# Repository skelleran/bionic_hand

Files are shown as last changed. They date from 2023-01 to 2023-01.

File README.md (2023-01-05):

# bionic_hand
A bionic hand controlled by a Raspberry Pi 4 connected to an ultrasonic sensor and camera. Uses TensorFlow Lite to detect objects and determine how to control the five connected servos.

pros_hand.py is the main code. I run it in a virtual environment on the Raspberry Pi 4, and it performs the full functionality described above. It requires the detection_model folder contents to perform object detection with Tensorflow Lite. Much of the object detection code was originally based on this sample code:
https://github.com/AnteZovko23/Machine_Learning-RaspberryPI_ObjectDetection_TensorFlow_OpenCV/blob/master/ObjectDetection2.py

detection_model contains the trained model, along with a text document, gripinfo.txt, that contains important information for pros_hand.py. The first column in the document contains labels for each possible classification, which is referenced by the index outputted by the trained model. The next five columns contain finger positions for their respective object so that pros_hand.py can specialize the grip to the targeted object.

solidworks_parts contains the parts I used to design the hand in solidworks. I recommend using the assembly to navigate between parts. Almost everything in the folder was designed by myself, with these exceptions:

Raspberry Pi Camera: https://grabcad.com/library/raspberry-pi-camera-v2-1

MG996R Servo: https://grabcad.com/library/servo-mg-996r-2

Ultrasonic Sensor: https://grabcad.com/library/ultrasonic-sensor-hc-sr04-5

printable_stl_parts contains stl parts exported from solidworks for printing, and everything in it is my original design.

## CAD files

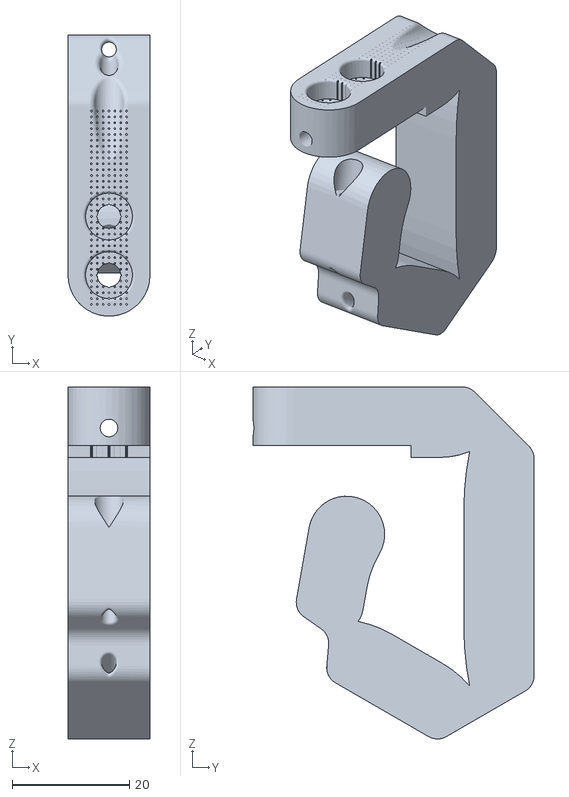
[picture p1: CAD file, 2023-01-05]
printable_stl_parts/Index Finger v2.STL
14.0 x 48.0 x 60.1

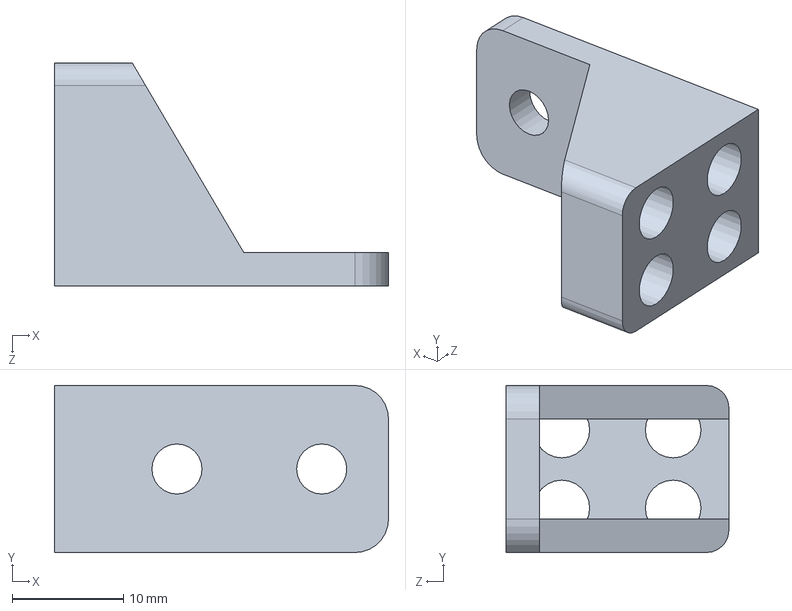
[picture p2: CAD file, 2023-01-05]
solidworks_parts/Servo Bracket.SLDPRT
30.0 x 15.0 x 20.0 mm

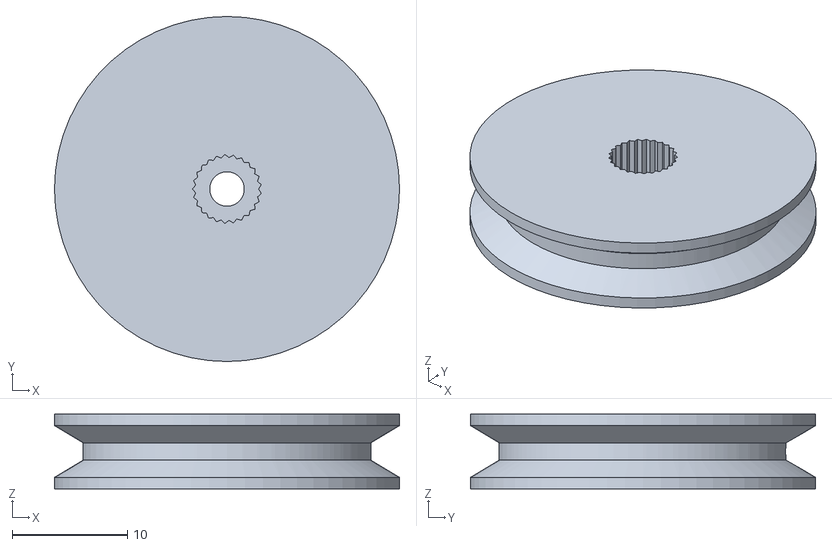
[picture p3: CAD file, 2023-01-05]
printable_stl_parts/Ass servo.STL
30.0 x 30.0 x 6.50

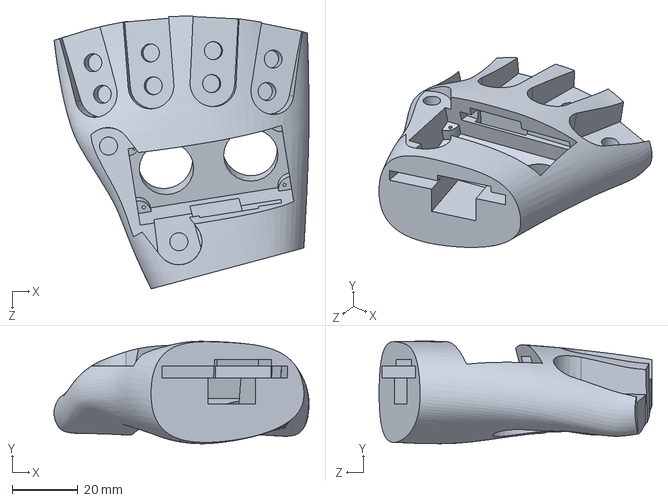
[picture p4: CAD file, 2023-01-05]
solidworks_parts/Big Hand.SLDPRT
77.3 x 31.1 x 82.7 mm

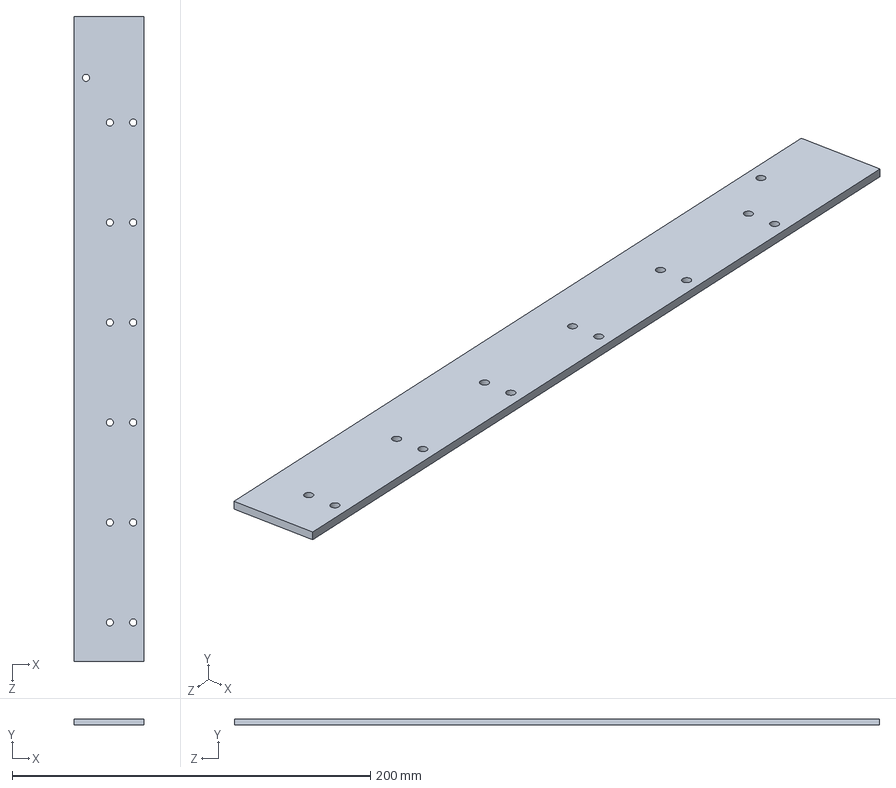
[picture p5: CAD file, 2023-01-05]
solidworks_parts/Aluminum Bar.SLDPRT
39.0 x 3.50 x 360.0 mm

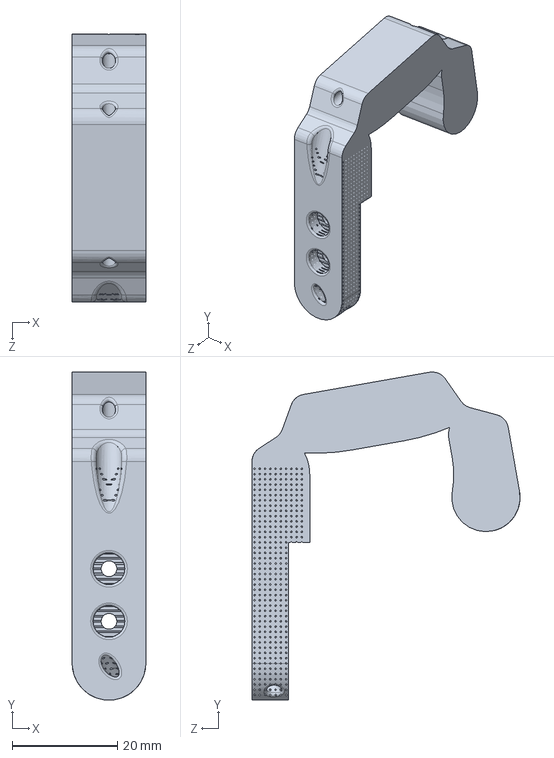
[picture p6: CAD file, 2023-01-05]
solidworks_parts/Thumb Finger.SLDPRT
14.0 x 62.4 x 51.0 mm

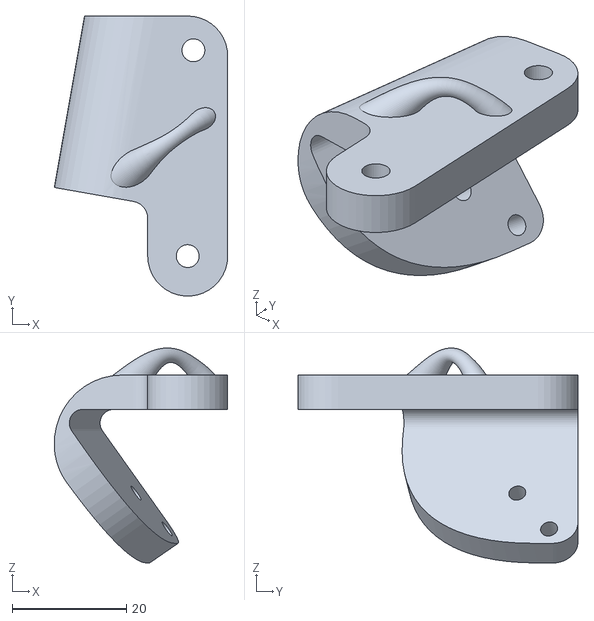
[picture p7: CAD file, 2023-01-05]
printable_stl_parts/Thumb base v2.STL
30.3 x 49.0 x 37.6

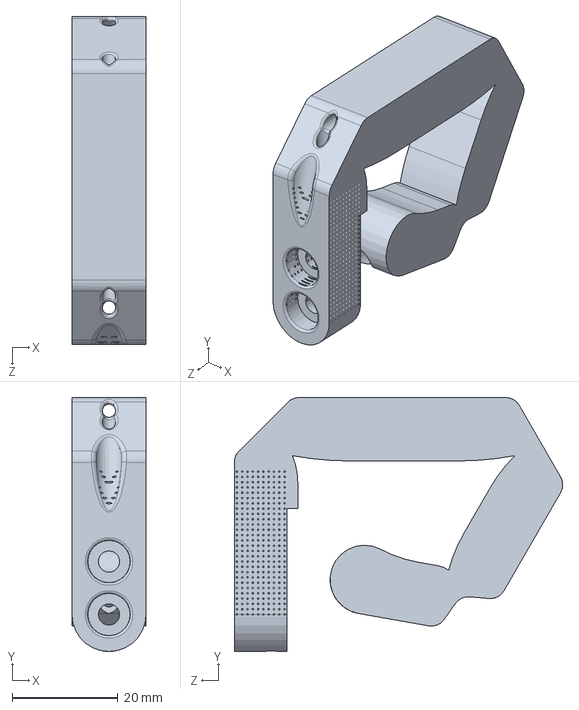
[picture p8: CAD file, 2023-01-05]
solidworks_parts/Middle Finger.SLDPRT
14.0 x 48.0 x 62.1 mm

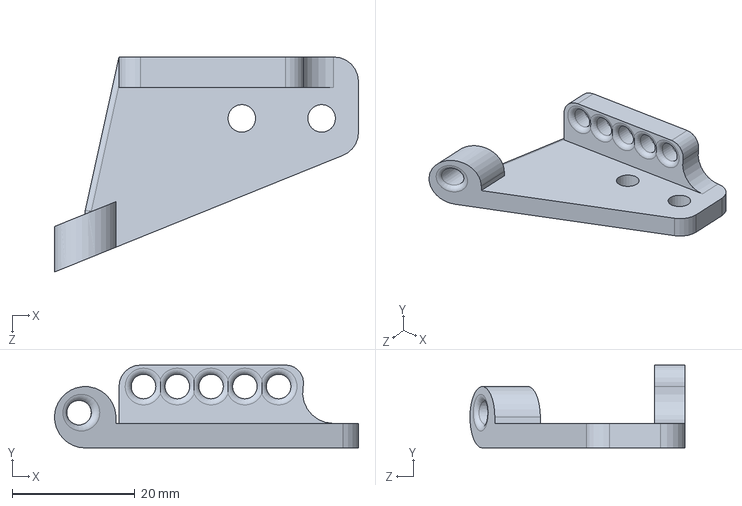
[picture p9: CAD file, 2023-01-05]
solidworks_parts/Wire Bracket.SLDPRT
49.5 x 13.5 x 35.0 mm

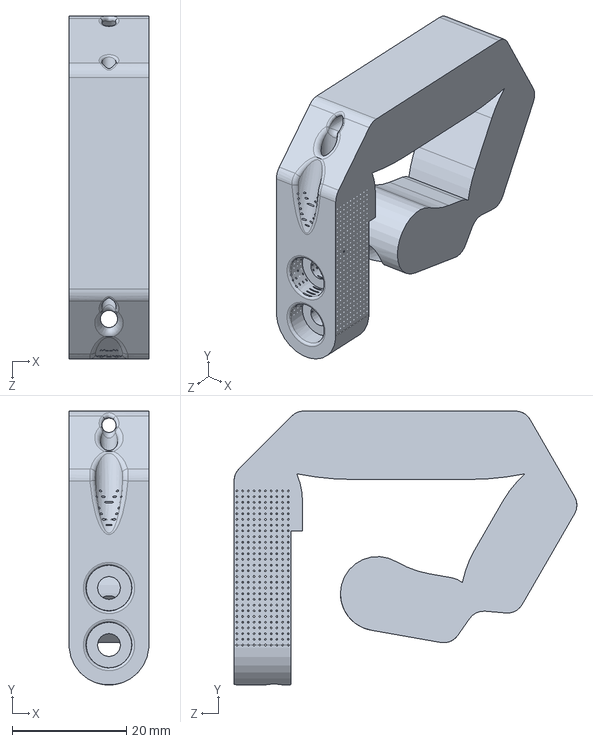
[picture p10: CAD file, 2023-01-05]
solidworks_parts/Index Finger.SLDPRT
14.0 x 48.0 x 60.1 mm

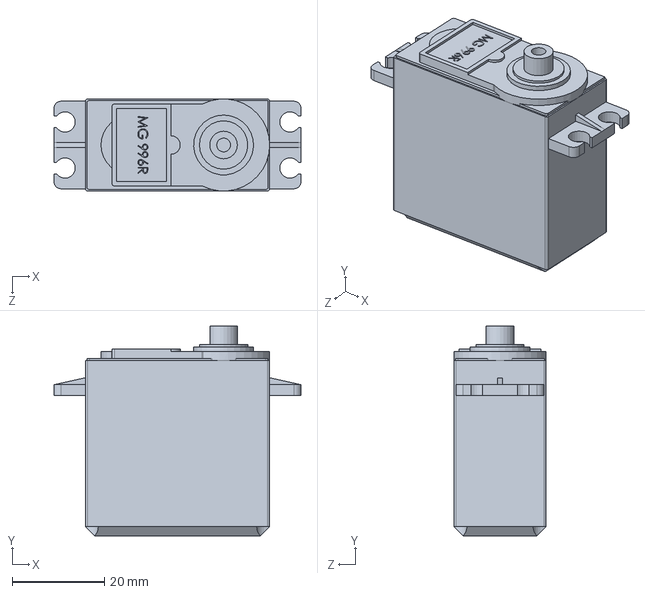
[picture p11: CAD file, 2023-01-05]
solidworks_parts/Servo_MG_996R.SLDPRT
53.6 x 45.5 x 20.0 mm

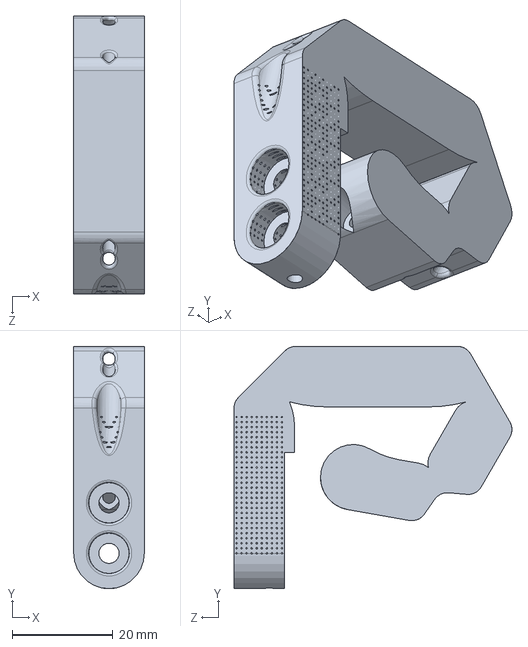
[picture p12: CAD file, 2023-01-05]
solidworks_parts/Pinkie Finger.SLDPRT
14.0 x 48.0 x 55.1 mm

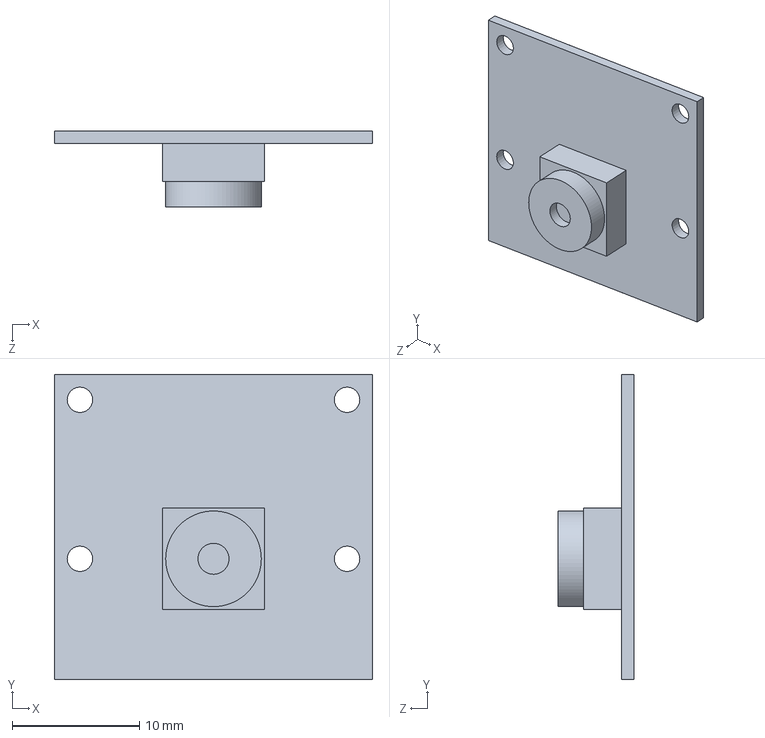
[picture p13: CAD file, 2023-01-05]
solidworks_parts/Raspberry Pi Camera.SLDPRT
25.0 x 24.0 x 6.00 mm

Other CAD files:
printable_stl_parts/Big Hand v1.STL
printable_stl_parts/Servo Bracket v2.STL
solidworks_parts/Servo Spool.SLDPRT
solidworks_parts/Thumb base.SLDPRT
printable_stl_parts/Index Finger.STL
printable_stl_parts/Servo Bracket.STL
printable_stl_parts/Thumb Finger.STL
printable_stl_parts/Thumb base.STL
printable_stl_parts/Wire Bracket.STL

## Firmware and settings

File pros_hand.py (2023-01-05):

######## Bionic Hand Conroller #########
#
# Author: Sam Kelleran
# Date: 1/1/23
# Description: 
# Controls bionic hand servos based on object dectection and ultrasonic distance sensor
# 
# Object recognition code is based off Evan Juras' TensorFlow Lite object detection example at:
# https://github.com/AnteZovko23/Machine_Learning-RaspberryPI_ObjectDetection_TensorFlow_OpenCV/blob/master/ObjectDetection2.py
#
# Import packages
import os
import argparse
import cv2
import numpy as np
import sys
import time
from threading import Thread
import importlib.util
import pandas as pd
import csv

from gpiozero import AngularServo, Device
import RPi.GPIO as GPIO
from gpiozero.pins.pigpio import PiGPIOFactory

Device.pin_factory = PiGPIOFactory()

#set ultrasonic sensor signal pins
TRIG = 21
ECHO = 20

#set offsets if fingers are opening too far
THUMB_OFFSET = 50
INDEX_OFFSET = 0
MIDDLE_OFFSET = 15
RING_OFFSET = 25
PINKIE_OFFSET = 0

#assign servos
thumb_servo = AngularServo(27, min_pulse_width=0.0006, max_pulse_width=0.0023)
index_servo = AngularServo(23, min_pulse_width=0.0006, max_pulse_width=0.0023 )
middle_servo = AngularServo(22, min_pulse_width=0.0006, max_pulse_width=0.0023)
ring_servo = AngularServo(24, min_pulse_width=0.0006, max_pulse_width=0.0023)
pinkie_servo = AngularServo(17, min_pulse_width=0.0006, max_pulse_width=0.0023)

#initialize ultrasonic sensor pins
GPIO.setmode(GPIO.BCM)
GPIO.setup(TRIG, GPIO.OUT)
GPIO.setup(ECHO, GPIO.IN)

# Define VideoStream class to handle streaming of video from webcam in separate processing thread
# Source - Adrian Rosebrock, PyImageSearch: https://www.pyimagesearch.com/2015/12/28/increasing-raspberry-pi-fps-with-python-and-opencv/
class VideoStream:
    """Camera object that controls video streaming from the Picamera"""
    def __init__(self,resolution=(640,480),framerate=30):
        # Initialize the PiCamera and the camera image stream
        self.stream = cv2.VideoCapture(0)
        ret = self.stream.set(cv2.CAP_PROP_FOURCC, cv2.VideoWriter_fourcc(*'MJPG'))
        ret = self.stream.set(3,resolution[0])
        ret = self.stream.set(4,resolution[1])
            
        # Read first frame from the stream
        (self.grabbed, self.frame) = self.stream.read()

	# Variable to control when the camera is stopped
        self.stopped = False

    def start(self):
	# Start the thread that reads frames from the video stream
        Thread(target=self.update,args=()).start()
        return self

    def update(self):
        # Keep looping indefinitely until the thread is stopped
        while True:
            # If the camera is stopped, stop the thread
            if self.stopped:
                # Close camera resources
                self.stream.release()
                return

            # Otherwise, grab the next frame from the stream
            (self.grabbed, self.frame) = self.stream.read()

    def read(self):
	# Return the most recent frame
        return self.frame

    def stop(self):
	# Indicate that the camera and thread should be stopped
        self.stopped = True

# Define and parse input arguments
parser = argparse.ArgumentParser()
parser.add_argument('--modeldir', help='Folder the .tflite file is located in',
                    default='Sample_TFLite_model')
parser.add_argument('--graph', help='Name of the .tflite file, if different than detect.tflite',
                    default='detect.tflite')
parser.add_argument('--labels', help='Name of the labelmap file, if different than labelmap.txt',
                    default='gripinfo.txt')
parser.add_argument('--resolution', help='Desired webcam resolution in WxH. If the webcam does not support the resolution entered, errors may occur.',
                    default='1280x720')
parser.add_argument('--edgetpu', help='Use Coral Edge TPU Accelerator to speed up detection',
                    action='store_true')

args = parser.parse_args()

MODEL_NAME = args.modeldir
GRAPH_NAME = args.graph
LABELMAP_NAME = args.labels
min_conf_threshold = 0.6
resW, resH = args.resolution.split('x')
imW, imH = int(resW), int(resH)
use_TPU = args.edgetpu

focus = -1
counter = 0

#returns the highest confidence object near the center of the frame, if confidence is above 60%
def get_item(boxes, classes, scores):
    best_class = -1
    ymin = int(boxes[0][0] * imH)
    xmin = int(boxes[0][1] * imW)
    ymax = int(boxes[0][2] * imH)
    xmax = int(boxes[0][3] * imW)
    
    x_center = (xmin + xmax) / 2
    y_center = (ymin + ymax) / 2
    
    if (abs(x_center - (imW / 2)) < 100) and (abs(y_center - (imH / 2)) < 100):
        if scores[0] > 0.6:
            best_class = classes[0]
            
    return best_class

#checks distance from ultrasonic sensor
def get_distance():
    GPIO.output(TRIG, True)
    time.sleep(0.00001)
    GPIO.output(TRIG, False)
    while GPIO.input(ECHO) == 0:
        pulse_start = time.time()
    while GPIO.input(ECHO) == 1:
        pulse_end = time.time()
    pulse_duration = pulse_end - pulse_start
    distance = pulse_duration*17150
    distance = round(distance, 2)
    return distance

#get a new finger angle depending on proximity to object to get ready to grab
def get_angle(distance):
    if distance > 15:
        angle = -90
    elif distance < 4:
        angle = -30
    else:
        angle = -30 - distance*4
    return angle

#sets all fingers to one angle
def set_fingers(angle):
    thumb_servo.angle = min(90, angle + THUMB_OFFSET)
    index_servo.angle = min(90, angle + INDEX_OFFSET)
    middle_servo.angle = min(90, angle + MIDDLE_OFFSET)
    ring_servo.angle = min(90, angle + RING_OFFSET)
    pinkie_servo.angle = min(90, angle + PINKIE_OFFSET)
        
#grabs object based on the values in grips.csv
def hold(focus):
    thumb_servo.angle = min(90, gripinfo[int(focus)][1] + THUMB_OFFSET)
    index_servo.angle = min(90, gripinfo[int(focus)][2] +   INDEX_OFFSET)
    middle_servo.angle = min(90, gripinfo[int(focus)][3] + MIDDLE_OFFSET)
    ring_servo.angle = min(90, gripinfo[int(focus)][4] + RING_OFFSET)
    pinkie_servo.angle = min(90, gripinfo[int(focus)][5] + PINKIE_OFFSET)
    time.sleep(10)

#starts measuring distance and adjusting fingers, once it gets within 6cm, hold() is called
def grab(focus):
    GPIO.output(TRIG, False)    
    t_end = time.time() + 10
    while time.time() < t_end:
        time.sleep(0.05)
        distance = get_distance()
        angle = get_angle(distance)
        if distance < 6:
            hold(focus)
        set_fingers(angle)

# Import TensorFlow libraries
# If tflite_runtime is installed, import interpreter from tflite_runtime, else import from regular tensorflow
# If using Coral Edge TPU, import the load_delegate library
pkg = importlib.util.find_spec('tflite_runtime')
if pkg:
    from tflite_runtime.interpreter import Interpreter
    if use_TPU:
        from tflite_runtime.interpreter import load_delegate
else:
    from tensorflow.lite.python.interpreter import Interpreter
    if use_TPU:
        from tensorflow.lite.python.interpreter import load_delegate

# If using Edge TPU, assign filename for Edge TPU model
if use_TPU:
    # If user has specified the name of the .tflite file, use that name, otherwise use default 'edgetpu.tflite'
    if (GRAPH_NAME == 'detect.tflite'):
        GRAPH_NAME = 'edgetpu.tflite'       

# Get path to current working directory
CWD_PATH = os.getcwd()

# Path to .tflite file, which contains the model that is used for object detection
PATH_TO_CKPT = os.path.join(CWD_PATH,MODEL_NAME,GRAPH_NAME)

# Path to label map file
PATH_TO_LABELS = os.path.join(CWD_PATH,MODEL_NAME,LABELMAP_NAME)

# Load the label map
#with open(PATH_TO_LABELS, 'r') as f:
#    labels = [line.strip() for line in f.readlines()]

#load grip vectors and seperate labels into a list
print(PATH_TO_LABELS)
gripinfo = []
with open(PATH_TO_LABELS, 'r') as f:
    reader = csv.reader(f, delimiter=',')
    for row in reader:
        gripinfo.append([(element if i == 0 else float(element)) for i, element in enumerate(row)])

labels = [row[0] for row in gripinfo]


# Have to do a weird fix for label map if using the COCO "starter model" from
# https://www.tensorflow.org/lite/models/object_detection/overview
# First label is '???', which has to be removed.
#if labels[0] == '???':
#    del(labels[0])

# Load the Tensorflow Lite model.
# If using Edge TPU, use special load_delegate argument
if use_TPU:
    interpreter = Interpreter(model_path=PATH_TO_CKPT,
                              experimental_delegates=[load_delegate('libedgetpu.so.1.0')])
    print(PATH_TO_CKPT)
else:
    interpreter = Interpreter(model_path=PATH_TO_CKPT)

interpreter.allocate_tensors()

# Get model details
input_details = interpreter.get_input_details()
output_details = interpreter.get_output_details()
height = input_details[0]['shape'][1]
width = input_details[0]['shape'][2]

floating_model = (input_details[0]['dtype'] == np.float32)

input_mean = 127.5
input_std = 127.5

# Check output layer name to determine if this model was created with TF2 or TF1,
# because outputs are ordered differently for TF2 and TF1 models
outname = output_details[0]['name']

if ('StatefulPartitionedCall' in outname): # This is a TF2 model
    boxes_idx, classes_idx, scores_idx = 1, 3, 0
else: # This is a TF1 model
    boxes_idx, classes_idx, scores_idx = 0, 1, 2

# Initialize frame rate calculation
frame_rate_calc = 1
freq = cv2.getTickFrequency()

# Initialize video stream
videostream = VideoStream(resolution=(imW,imH),framerate=30).start()
time.sleep(1)

#open fingers
set_fingers(-90)

#for frame1 in camera.capture_continuous(rawCapture, format="bgr",use_video_port=True):
while True:

    # Start timer (for calculating frame rate)
    t1 = cv2.getTickCount()

    # Grab frame from video stream
    frame1 = videostream.read()

    # Acquire frame and resize to expected shape [1xHxWx3]
    frame = frame1.copy()
    frame_rgb = cv2.cvtColor(frame, cv2.COLOR_BGR2RGB)
    frame_resized = cv2.resize(frame_rgb, (width, height))
    input_data = np.expand_dims(frame_resized, axis=0)

    # Normalize pixel values if using a floating model (i.e. if model is non-quantized)
    if floating_model:
        input_data = (np.float32(input_data) - input_mean) / input_std

    # Perform the actual detection by running the model with the image as input
    interpreter.set_tensor(input_details[0]['index'],input_data)
    interpreter.invoke()

    # Retrieve detection results
    boxes = interpreter.get_tensor(output_details[boxes_idx]['index'])[0] # Bounding box coordinates of detected objects
    classes = interpreter.get_tensor(output_details[classes_idx]['index'])[0] # Class index of detected objects
    scores = interpreter.get_tensor(output_details[scores_idx]['index'])[0] # Confidence of detected objects

    # Loop over all detections and draw detection box if confidence is above minimum threshold
    for i in range(len(scores)):
        if ((scores[i] > min_conf_threshold) and (scores[i] <= 1.0)):

            # Get bounding box coordinates and draw box
            # Interpreter can return coordinates that are outside of image dimensions, need to force them to be within image using max() and min()
            ymin = int(max(1,(boxes[i][0] * imH)))
            xmin = int(max(1,(boxes[i][1] * imW)))
            ymax = int(min(imH,(boxes[i][2] * imH)))
            xmax = int(min(imW,(boxes[i][3] * imW)))
            
            cv2.rectangle(frame, (xmin,ymin), (xmax,ymax), (10, 255, 0), 2)

            # Draw label
            print(type(labels))
            print(classes[i])
            object_name = labels[int(classes[i])] # Look up object name from "labels" array using class index
            label = '%s: %d%%' % (object_name, int(scores[i]*100)) # Example: 'person: 72%'
            labelSize, baseLine = cv2.getTextSize(label, cv2.FONT_HERSHEY_SIMPLEX, 0.7, 2) # Get font size
            label_ymin = max(ymin, labelSize[1] + 10) # Make sure not to draw label too close to top of window
            cv2.rectangle(frame, (xmin, label_ymin-labelSize[1]-10), (xmin+labelSize[0], label_ymin+baseLine-10), (255, 255, 255), cv2.FILLED) # Draw white box to put label text in
            cv2.putText(frame, label, (xmin, label_ymin-7), cv2.FONT_HERSHEY_SIMPLEX, 0.7, (0, 0, 0), 2) # Draw label text
    
    #Get highest confidence object in the center of the image
    temp_focus = get_item(boxes, classes, scores)
    
    # Draw framerate in corner of frame
    cv2.putText(frame,'FPS: {0:.2f}'.format(frame_rate_calc),(30,50),cv2.FONT_HERSHEY_SIMPLEX,1,(255,255,0),2,cv2.LINE_AA)
   
    if temp_focus == -1:
        #no focus, no count
        counter = 0
        focus = -1
    elif temp_focus == focus:
        #holding focus, continue count
        counter = counter + 1
    else:
        #new focus, start count
        counter = 1
        focus = temp_focus
    
    if counter >= 5:
        #grab sequence
        #draw grab alert in middle of frame
        cv2.putText(frame,'FOCUS ACQUIRED',(100,200),cv2.FONT_HERSHEY_SIMPLEX,3,(255,255,0),2,cv2.LINE_AA)
        # All the results have been drawn on the frame, so it's time to display it.
        cv2.imshow('Object detector', frame)
        cv2.waitKey(30)
        #perform grab
        grab(focus)
        #open fingers
        set_fingers(-90)
        counter = 0
        focus = -1
    
    

    # All the results have been drawn on the frame, so it's time to display it.
    cv2.imshow('Object detector', frame)

    # Calculate framerate
    t2 = cv2.getTickCount()
    time1 = (t2-t1)/freq
    frame_rate_calc= 1/time1

    # Press 'q' to quit
    if cv2.waitKey(1) == ord('q'):
        break
    
# Clean up
print("clean up")
set_fingers(50)
GPIO.cleanup()
cv2.destroyAllWindows()
videostream.stop()

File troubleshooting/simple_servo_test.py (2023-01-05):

from gpiozero import AngularServo, Device
import time

import RPi.GPIO as GPIO

from gpiozero.pins.pigpio import PiGPIOFactory

Device.pin_factory = PiGPIOFactory()

ANGLE1 = 40
ANGLE2 = -90

DELAY1 = 0.15

thumb_servo = AngularServo(27, min_pulse_width=0.0006, max_pulse_width=0.0023)
index_servo = AngularServo(23, min_pulse_width=0.0006, max_pulse_width=0.0023 )
middle_servo = AngularServo(22, min_pulse_width=0.0006, max_pulse_width=0.0023)
ring_servo = AngularServo(24, min_pulse_width=0.0006, max_pulse_width=0.0023)
pinkie_servo = AngularServo(17, min_pulse_width=0.0006, max_pulse_width=0.0023)

try:
    while (True):
        thumb_servo.angle = ANGLE1 + 50
        time.sleep(DELAY1)
        index_servo.angle = ANGLE1
        time.sleep(DELAY1)
        middle_servo.angle = ANGLE1 + 30
        time.sleep(DELAY1)
        ring_servo.angle = ANGLE1 + 25
        time.sleep(DELAY1)
        pinkie_servo.angle = ANGLE1
        time.sleep(2)
        thumb_servo.angle = ANGLE2 + 50
        time.sleep(DELAY1)
        index_servo.angle = ANGLE2
        time.sleep(DELAY1)
        middle_servo.angle = ANGLE2 + 20
        time.sleep(DELAY1)
        ring_servo.angle = ANGLE2 + 25
        time.sleep(DELAY1)
        pinkie_servo.angle = ANGLE2
        time.sleep(2)
        
finally:
    thumb_servo.angle = ANGLE1
    index_servo.angle = ANGLE1
    middle_servo.angle = ANGLE1
    ring_servo.angle = ANGLE1
    pinkie_servo.angle = ANGLE1
    print("clean up")
    GPIO.cleanup()
